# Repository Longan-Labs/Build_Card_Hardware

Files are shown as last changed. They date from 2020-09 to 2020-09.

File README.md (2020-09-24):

In the last post, we introduced how to modify and create the firmware of a Card. In this post, we will introduce how to create the hardware of a Card module.
If you want to know which Card modules are currently available, you can click the [link](http://docs.longan-labs.cc/cards-system-summary/) to get the list.

# Required skills

* Familiar with basic electronic circuit
* Familiar with Eagle CAD software

# Download a template

We provide a template of Eagle files to help you to develop quickly. You can click the [link](https://github.com/Longan-Labs/Build_Card_Hardware/archive/master.zip) to download the template.

Open the template and you'll find that the basic part of the schematic has been completed. You only need to add the components you need in the blank part on the left.

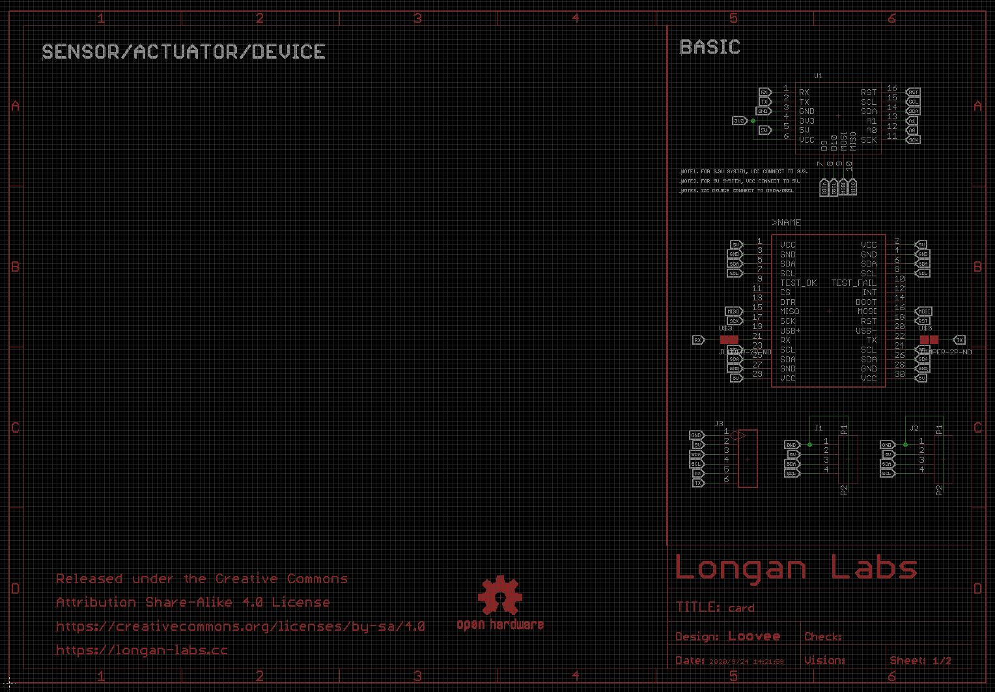
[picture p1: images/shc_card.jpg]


# How to design

In the schematic diagram, you can see a device called U1, which is the smallest system module of a single-chip microcomputer. The available interfaces are as follows:

* I2C x 1
* UART x 1
* SPI x 1
* Analog input x 2
* Digital Input/Output x 2

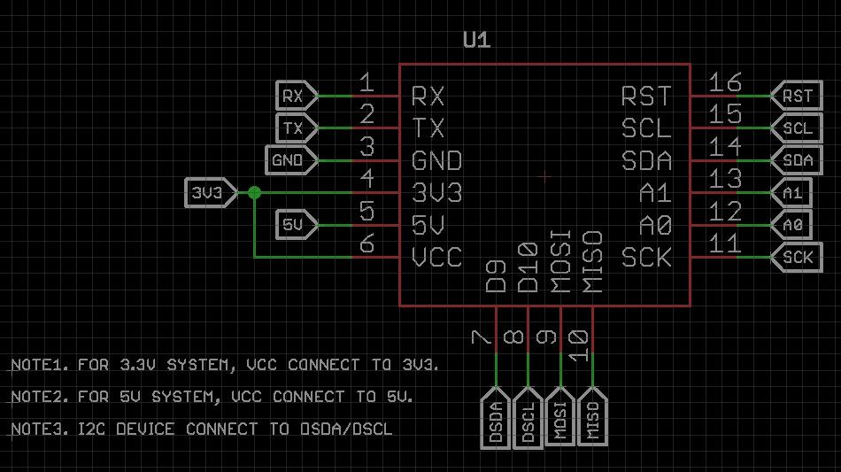
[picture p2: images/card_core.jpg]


If you use an I2C interface, please connect the I2C of the device to DSDA/DSCL. Similarly, for others interfaces, such as UART/SPI or Analog Input device, do the same things.

In addition, you should pay attention to the power supply. If the device you are using is 3.3V, you need to connect the VCC of U1 to 3V3 of U1, otherwise you can connect it to 5V

# one example

In order to prove that it is not difficult to create a Card module, here we take BME280 as an example to design a BME280 Card.
BME280 is a temperature, humidity and pressure sensor.

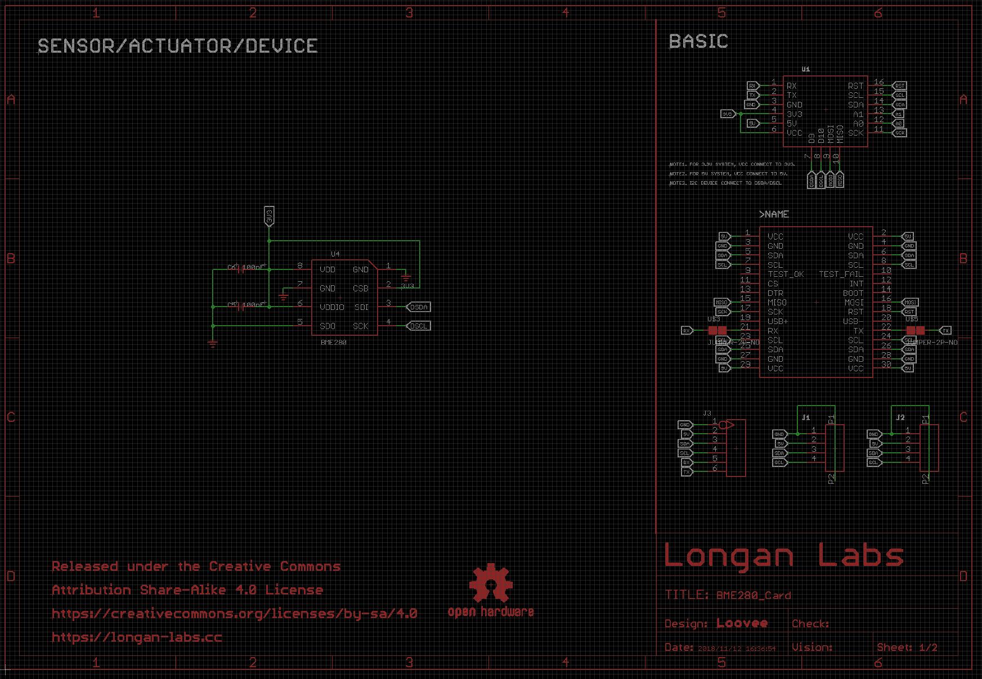
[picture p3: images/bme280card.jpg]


As you can see, we put in a BME280 chip, and made some simple connections, and we are done.
You can download Eagle File of BME280 Card for more information.

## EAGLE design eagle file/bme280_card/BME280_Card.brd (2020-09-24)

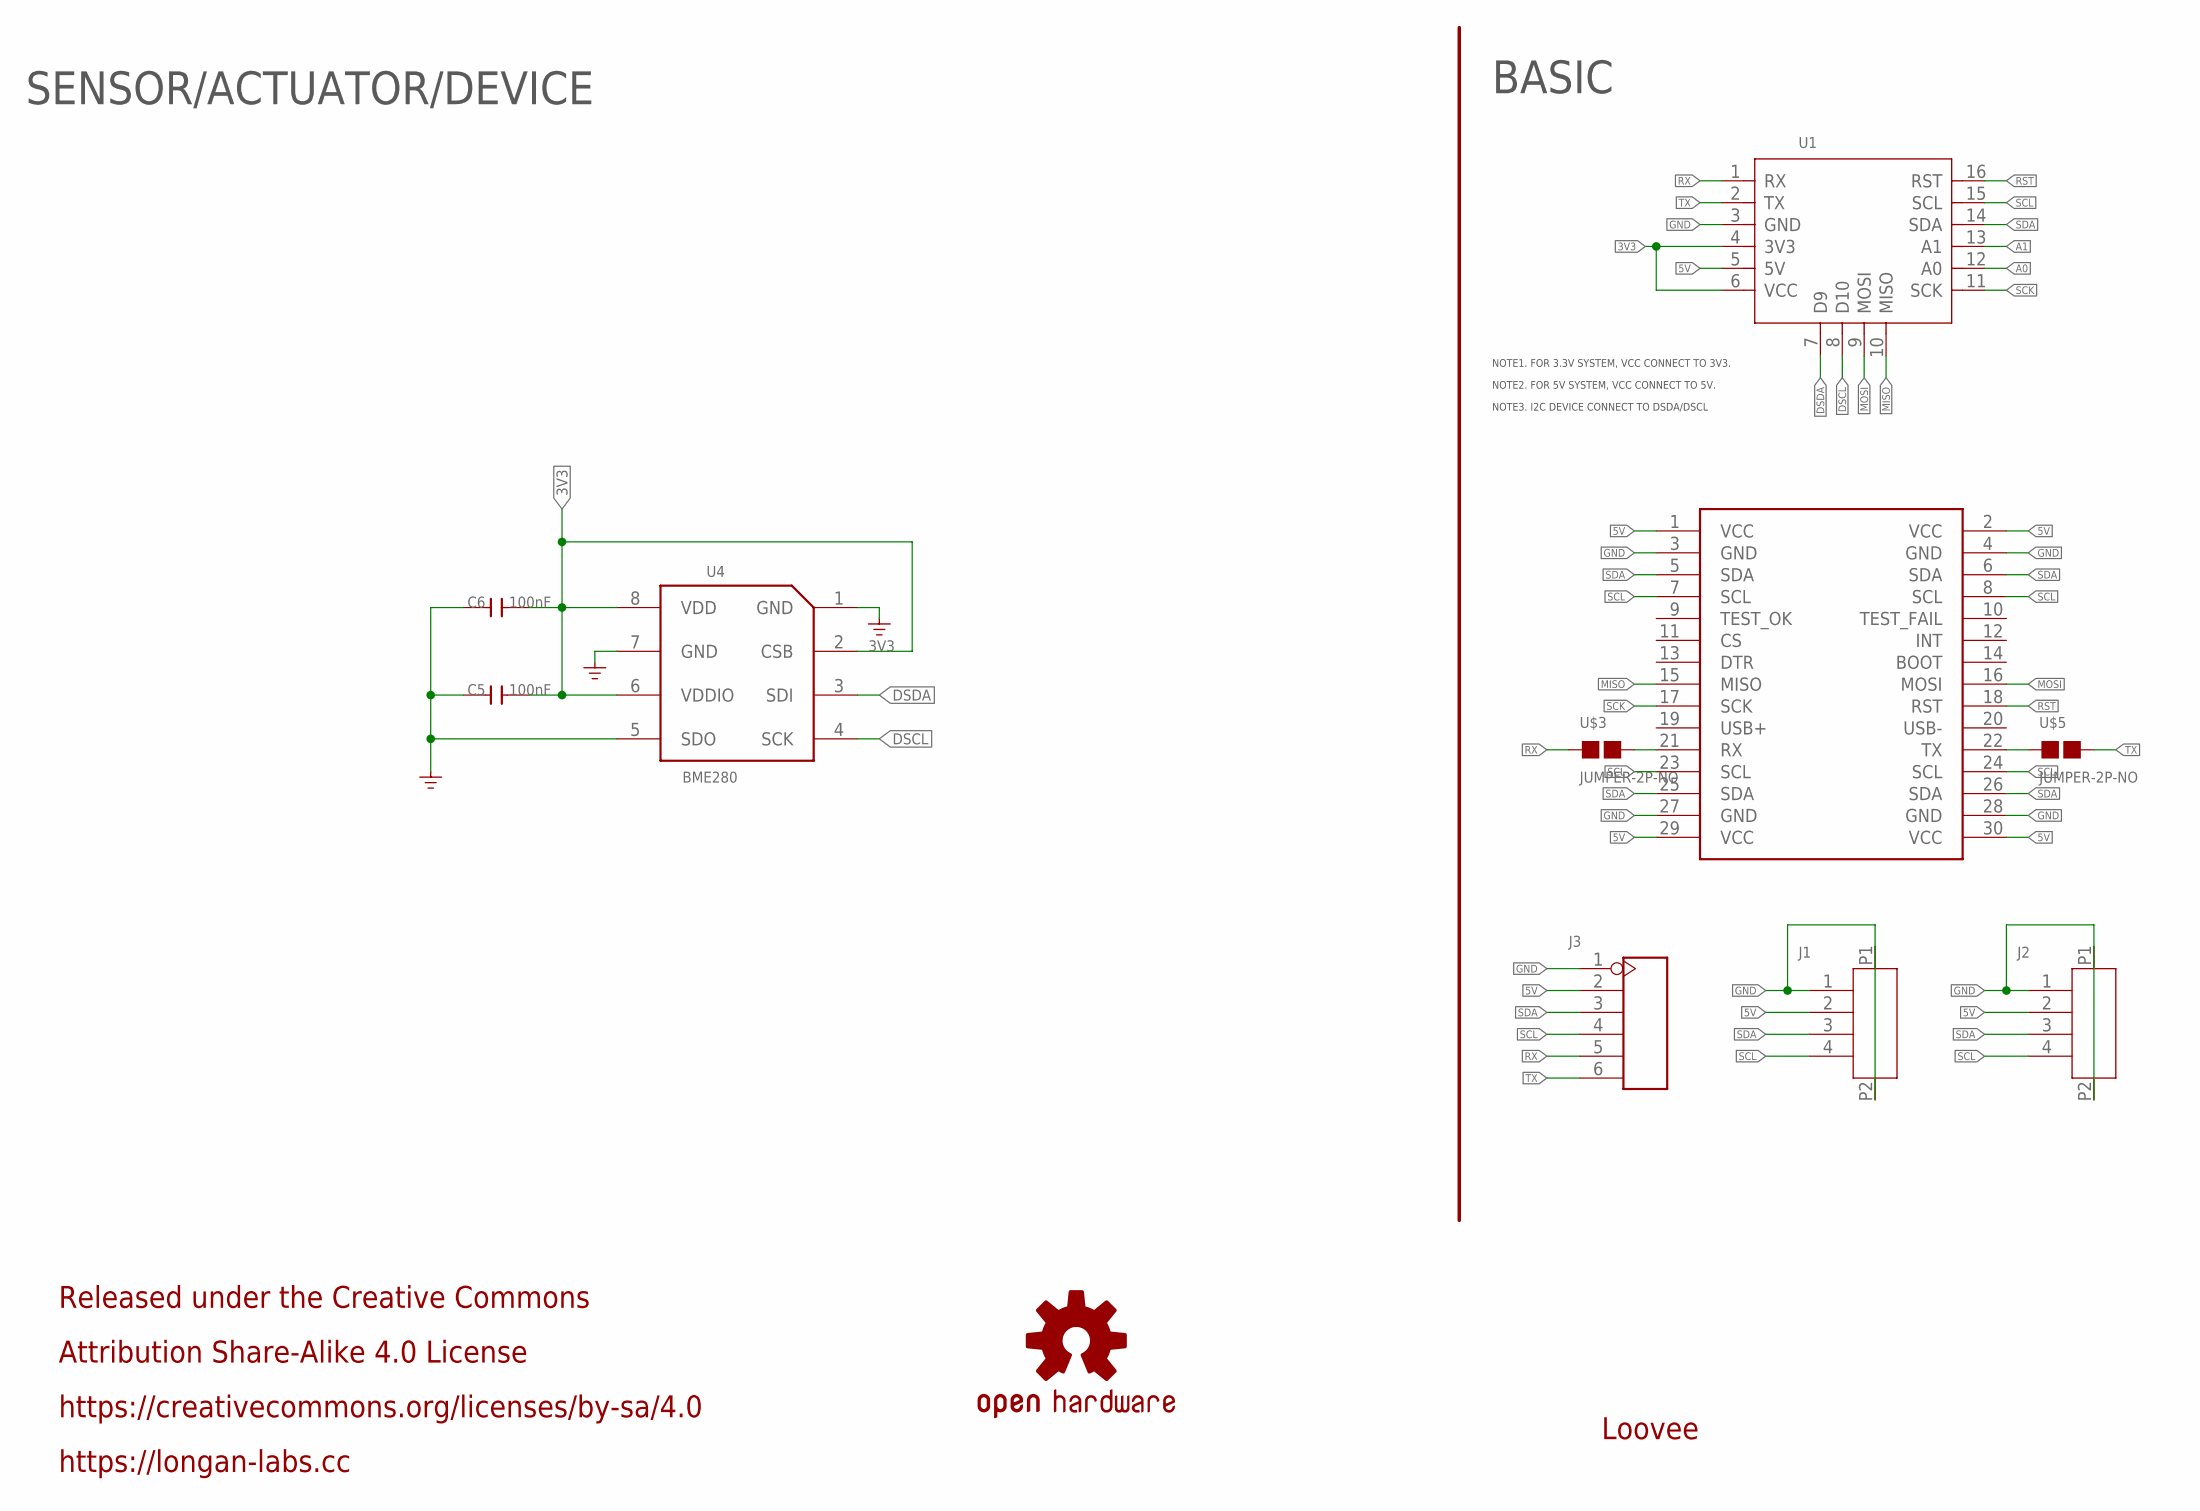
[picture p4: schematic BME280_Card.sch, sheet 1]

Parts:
C5, C6: 100nF; C0603
J1, J2: HEADER-4P-1.0; 4P-1.0-90D
J3: HEADER-6P-55/35MIL; H6-2.54
LOGO2: OSHW-LOGOS; OSHW-LOGO-S
MOUDLE1: MOUDLE-2X15P-2.54'BOARD'; MOUDLE-2X15P-2.54
U1: MOUDLE-CARDS; 16P-2.0-CARDS
U4: BME280; LGA8-0.65-2.5X2.5X0.95MM
U$3, U$5: JUMPER-2P-NO; 2P-SMD-NO

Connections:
3V3: C5.1, C6.1, U1.4 (3V3), U1.6 (VCC), U4.2 (CSB), U4.6 (VDDIO), U4.8 (VDD)
5V: J1.2, J2.2, J3.2, MOUDLE1.1 (VCC), MOUDLE1.2 (VCC), MOUDLE1.29 (VCC), MOUDLE1.30 (VCC), U1.5 (5V)
A0: U1.12 (A0)
A1: U1.13 (A1)
DSCL: U1.8 (D10), U4.4 (SCK)
DSDA: U1.7 (D9), U4.3 (SDI)
GND: C5.2, C6.2, J1.1, J1.P1, J1.P2, J2.1, J2.P1, J2.P2, J3.1, MOUDLE1.3 (GND), MOUDLE1.4 (GND), MOUDLE1.27 (GND), MOUDLE1.28 (GND), U1.3 (GND), U4.1 (GND), U4.5 (SDO), U4.7 (GND)
MISO: MOUDLE1.15 (MISO), U1.10 (MISO)
MOSI: MOUDLE1.16 (MOSI), U1.9 (MOSI)
unnamed: MOUDLE1.21 (RX), U$3.2
unnamed: MOUDLE1.22 (TX), U$5.1
RST: MOUDLE1.18 (RST), U1.16 (RST)
RX: J3.5, U1.1 (RX), U$3.1
SCK: MOUDLE1.17 (SCK), U1.11 (SCK)
SCL: J1.4, J2.4, J3.4, MOUDLE1.7 (SCL), MOUDLE1.8 (SCL), MOUDLE1.23 (SCL), MOUDLE1.24 (SCL), U1.15 (SCL)
SDA: J1.3, J2.3, J3.3, MOUDLE1.5 (SDA), MOUDLE1.6 (SDA), MOUDLE1.25 (SDA), MOUDLE1.26 (SDA), U1.14 (SDA)
TX: J3.6, U1.2 (TX), U$5.2

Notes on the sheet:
BASIC
Loovee
NOTE1. FOR 3.3V SYSTEM, VCC CONNECT TO 3V3.
NOTE2. FOR 5V SYSTEM, VCC CONNECT TO 5V.
NOTE3. I2C DEVICE CONNECT TO DSDA/DSCL
SENSOR/ACTUATOR/DEVICE
Released under the Creative Commons
Attribution Share-Alike 4.0 License
https://creativecommons.org/licenses/by-sa/4.0
https://longan-labs.cc

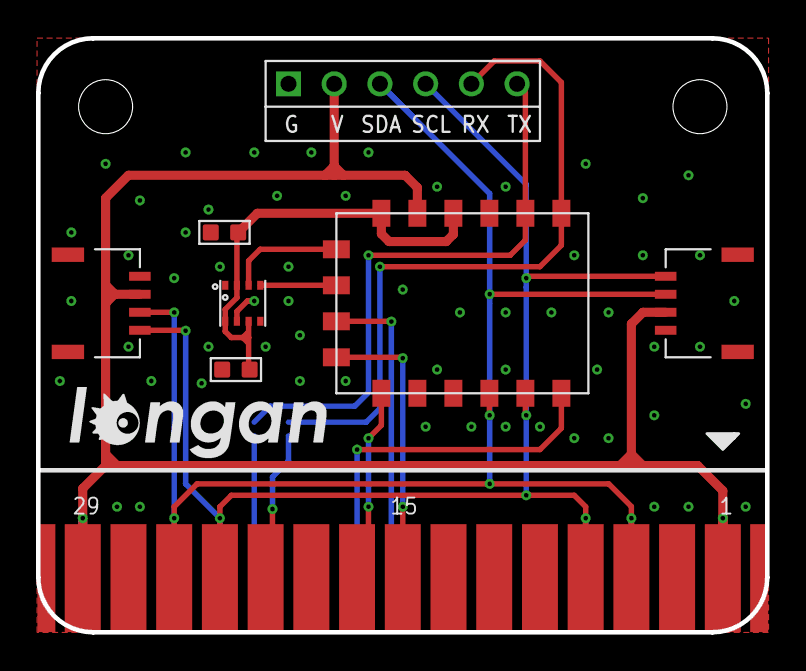
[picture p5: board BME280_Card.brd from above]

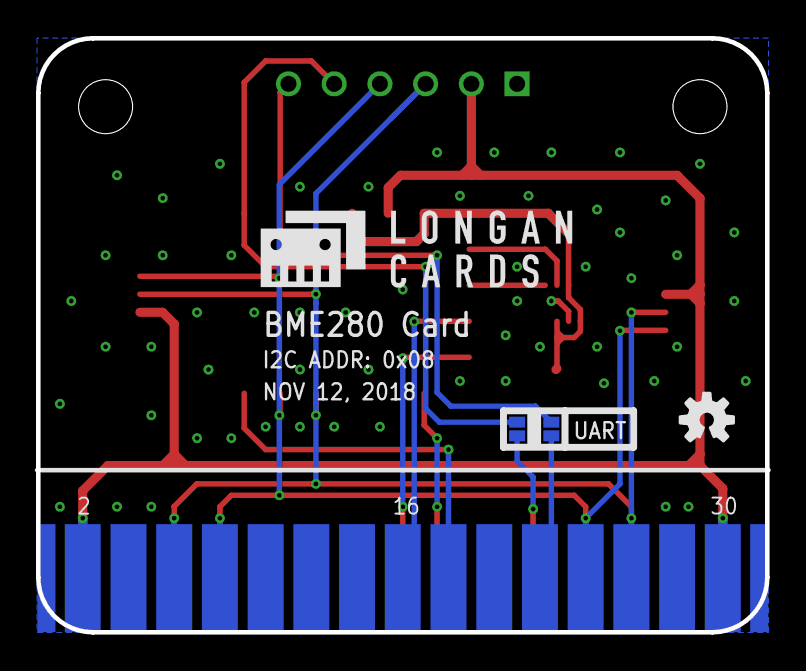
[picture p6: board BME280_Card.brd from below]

Board: 2 copper layers, 40.5 x 33.0 mm, 13 parts (4 on the bottom side), 15 nets.

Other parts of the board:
U$1: LONGAN-CARDS-MIDDLE
U$2: LONGAN-SILK-SMALLER

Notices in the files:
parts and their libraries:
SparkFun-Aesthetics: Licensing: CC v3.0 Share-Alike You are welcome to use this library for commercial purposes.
